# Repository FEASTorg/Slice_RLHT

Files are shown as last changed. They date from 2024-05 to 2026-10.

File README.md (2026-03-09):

# Sice RLHT

Relay Heating Element Controller Slice for BREAD.

## Introduction

[Provide a brief introduction to the project, including the motivation and goals. Explain the significance and context of the research.]

## Project Overview

[Describe the project in more detail. This section can be split into subsections if necessary.]

## Installation

[Provide instructions for installing any necessary software or hardware components.]

## Usage

[Explain how to use the project. Include examples and screenshots if applicable.]

### Basic Usage

[Provide basic usage instructions.]

### Advanced Usage

[Provide advanced usage instructions, including any optional features or configurations.]

## Documentation

[Link to the detailed documentation if available. Provide instructions on how to access and navigate the documentation.]

## Contributing

[Explain how others can contribute to the project. Include guidelines for submitting issues, pull requests, and any coding standards.]

### Code of Conduct

[Link to the project's code of conduct if available.]

## License

[State the license under which the project is distributed. Include a link to the full license text.]

## Acknowledgements

[Acknowledge any contributors, collaborators, funding sources, or organizations that supported the project.]

## Contact

[Provide contact information for the project maintainer(s) or lead researcher(s). Include an email address or a link to a contact form.]

---

<div align="center">
  <p>
    
    
  </p>
</div>

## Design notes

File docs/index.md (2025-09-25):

---
title: "Slice RLHT Documentation"
description: "Overview and entry page for Slice RLHT project documentation."
nav_exclude: true
---

Welcome to the Slice RLHT project documentation.

## Board Renders

<figure style="display:inline-block; text-align:center; margin:10px;">
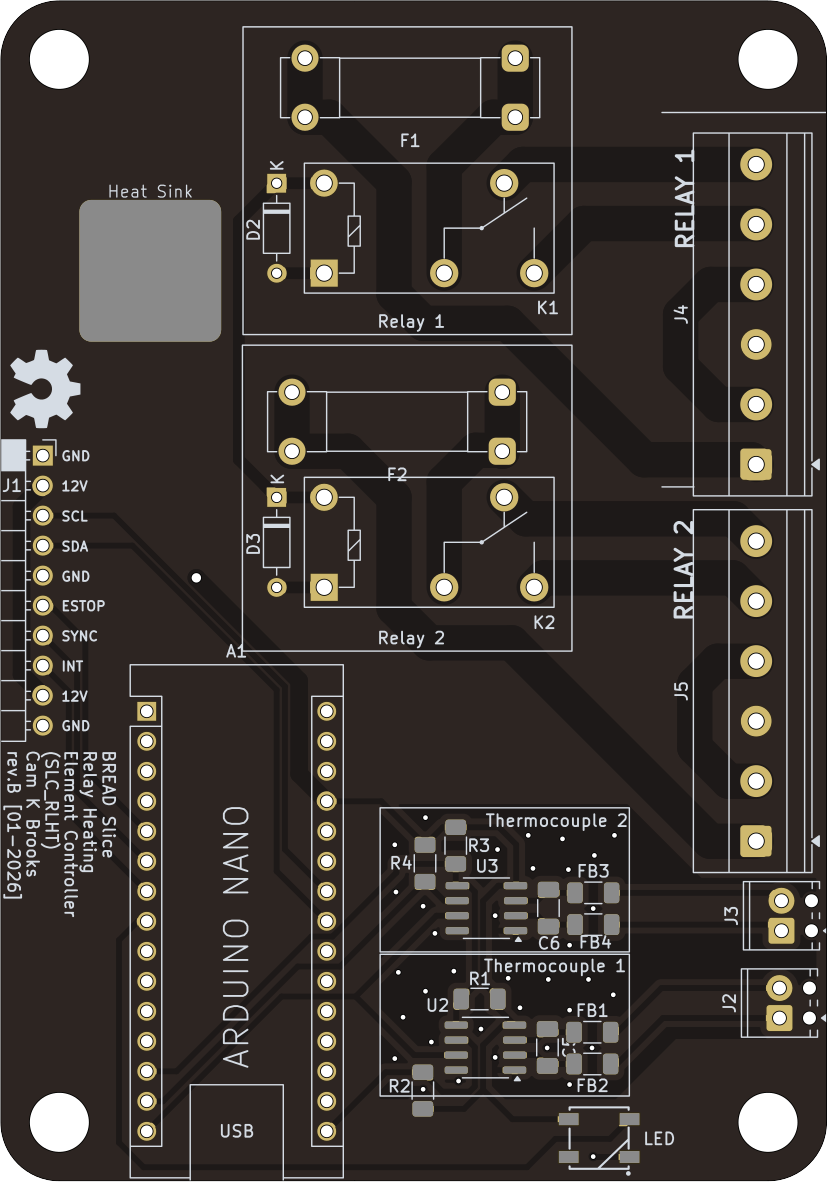
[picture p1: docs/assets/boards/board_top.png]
Board Top
  
  <figcaption>Top</figcaption>
</figure>

<figure style="display:inline-block; text-align:center; margin:10px;">
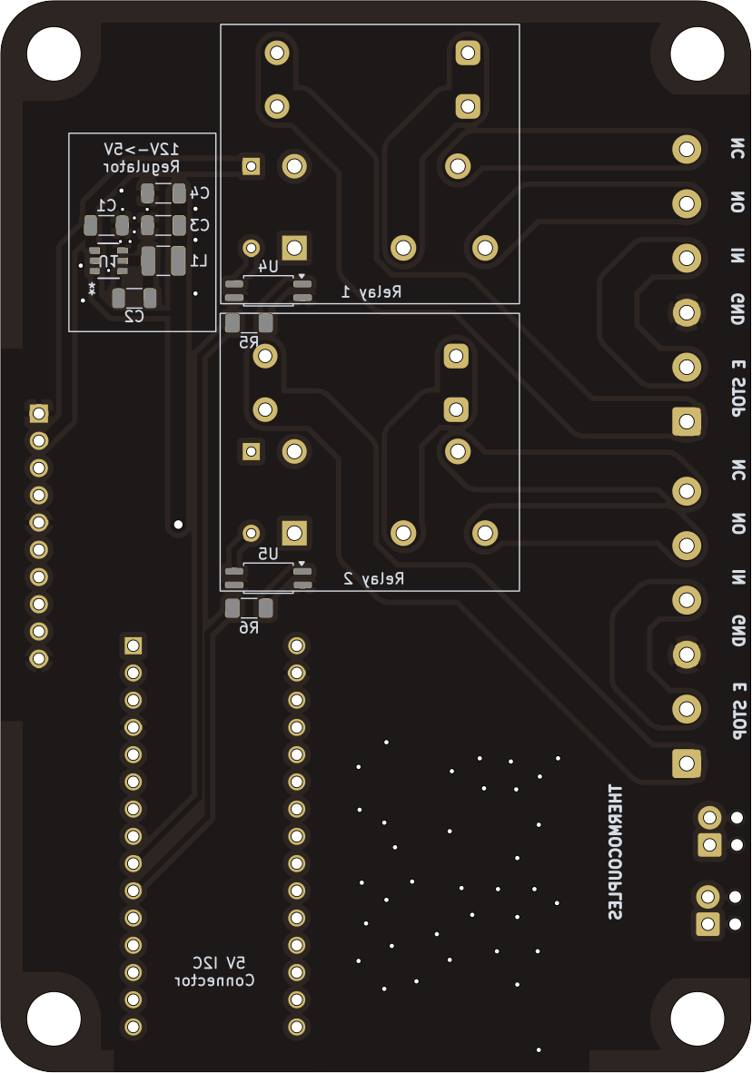
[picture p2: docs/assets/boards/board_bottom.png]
Board Bottom
  
  <figcaption>Bottom</figcaption>
</figure>

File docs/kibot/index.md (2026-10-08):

---
title: "KiBot Outputs"
description: "Index for KiBot-generated PCB artifacts."
layout: "page"
---

These are the docs & KiBot Outputs for Slice RLHT

The following files were generated from the latest PCB build:

- [Schematic.pdf](./Schematic.pdf)
- [PCB.pdf](./PCB.pdf)
- [kibot.log](./kibot.log)
- [BREAD_Slice-bom.html](./BREAD_Slice-bom.html)
- [BREAD_Slice-ibom.html](./BREAD_Slice-ibom.html)

_Last updated automatically on 2026-10-08 at 03:28:19 UTC by KiBot via GitHub Actions._

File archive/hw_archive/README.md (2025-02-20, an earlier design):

# Historical Hardware Progression

Cam notes:

- 2022-05-19 we dont have any in the lab to my knowledge
- 2022-06-30 is the green ones in the lab
- recent is the most recent one from Finn, has glass fuse
- still missing files for one with blade fuse

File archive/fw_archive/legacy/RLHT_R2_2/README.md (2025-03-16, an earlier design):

# RLHT R2.2 Firmware Docs

Notes on the firmware for relay heater slice.

## Commands

This system supports several types of serial commands that allow the user to control various aspects of the system, such as mode selection, relay input, heater setpoints, PID tuning, and emergency stop.

### 1. Mode Commands (`M`)

- **Format**: `M <mode>`
  - **Example**: `M 0` to switch to CONTROL mode (automatic PID control)
  - **Example**: `M 1` to switch to WRITE mode (manual control of relay inputs)

### 2. Write Relay Input (`W`)

- **Format**: `W <relay> <value>`
  - **Example**: `W 1 75` to set relay 1 input to 75% (value is clamped between 0 and 100)
  - **Example**: `W 2 50` to set relay 2 input to 50%

### 3. Heater Setpoint (`H`)

- **Format**: `H <heater> <setpoint>`
  - **Example**: `H 1 150.5` to set heater 1's temperature setpoint to 150.5°C
  - **Example**: `H 2 200` to set heater 2's temperature setpoint to 200°C

### 4. PID Tuning (`P`)

- **Format**: `P <heater> <Kp>,<Ki>,<Kd>`
  - **Example**: `P 1 2.5,0.1,0.01` to update PID values for heater 1 (Kp=2.5, Ki=0.1, Kd=0.01)
  - **Example**: `P 2 3.0,0.2,0.02` to update PID values for heater 2 (Kp=3.0, Ki=0.2, Kd=0.02)

### 5. Thermo Select (`S`)

- **Format**: `S <relay> <thermo>`
  - **Example**: `S 1 1` to set relay 1 to read from thermocouple 1
  - **Example**: `S 2 2` to set relay 2 to read from thermocouple 2

### Invalid Commands

- Any command that does not match the above patterns will result in an error message: `Invalid command!`

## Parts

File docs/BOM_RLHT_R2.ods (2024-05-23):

References | Value | Footprint | Quantity | URL
C1, C3, C4 | 22uF | C_1206_3216Metric | 3 | https://www.digikey.ca/en/products/detail/samsung-electro-mechanics/CL31A226KAHNNNE/3888705
C5, C6 | 0.01 uF | C_1206_3216Metric | 2 | https://www.digikey.ca/en/products/detail/walsin-technology-corporation/1206B103J500CT/9355096
C2 | 100nF | C_1206_3216Metric | 1 | https://www.digikey.ca/en/products/detail/samsung-electro-mechanics/CL31B104KBCNNNC/3886675
L1 | 4.7uH | L_1210_3225Metric | 1 | https://www.digikey.ca/en/products/detail/tdk-corporation/BCL322520RT-4R7M-D/15849704
D2, D3 | General_Purpose_Diode | D_DO-35_SOD27_P7.62mm_Horizontal | 2 | https://www.digikey.ca/en/products/detail/onsemi/1N914B/978757
D1 | WS2812B_5050 | WS2812-5050-4PIN | 1 | https://www.digikey.ca/en/products/detail/sparkfun-electronics/COM-16347/11630204
U2, U5 | TCMT1100 | SOP-4_4.4x2.6mm_P1.27mm | 2 | https://www.digikey.ca/en/products/detail/vishay-semiconductor-opto-division/TCMT1100/1738630
U3, U4 | MAX6675ISA+ | SOIC127P600X175-8N | 2 | https://www.digikey.ca/en/products/detail/maxim-integrated/MAX6675ISA/1513517
U1 | AP63205WU-7 | TSOT-23-6 | 1 | https://www.digikey.ca/en/products/detail/diodes-incorporated/AP63205WU-7/9858424
F1, F2 | 10A | Glass Fuse Clip x2 (5x20MM) | 4 | https://www.digikey.ca/en/products/detail/bel-fuse-inc/FC-211-BRIGHT-TIN/622587
A1 | Arduino_Nano_v3.x | Arduino_Nano | 1 | https://www.amazon.ca/ELEGOO-Arduino-ATmega328P-Without-Compatible/dp/B0713XK923
FB1, FB2, FB3, FB4 | Ferrite_Bead_Small | R_1206_3216Metric | 4 | https://www.digikey.ca/en/products/detail/w%C3%BCrth-elektronik/74279215/1639033
K1, K2 | G5Q-1 | Relay_SPDT_Omron-G5Q-1 | 2 | https://www.digikey.ca/en/products/detail/omron-electronics-inc-emc-div/G5Q-14-DC12/355243
HS1 | Heatsink_Pad (optional) | Thermal Pad | 1 | https://www.digikey.ca/en/products/detail/assmann-wsw-components/V2017B/3511410
J4 | Term_PressFit_Phoenix_Contact | Term_PressFit_3.5mm_H_ENDCAP_PC | 1 (4x) | https://www.digikey.ca/en/products/detail/phoenix-contact/1990753/2527254
J3, J11, J12 | Term_PressFit_Phoenix_Contact | Term_PressFit_3.5mm_H_PC
J1 | Conn_01x10_Female | PinSocket_1x10_P2.54mm_Horizontal | 1 | https://www.digikey.ca/en/products/detail/sullins-connector-solutions/PPTC101LGBN-RC/775904
J2 | I2C_01x04 | JST_SH_SM04B-SRSS-TB_1x04-1MP_P1.00mm_Horizontal | 1 | https://www.digikey.ca/en/products/detail/jst-sales-america-inc/SM04B-SRSS-TB/926710
J6, J7, J8, J9, J10, J13, J14, J15, J16, J17, J18 | Term_PressFit_Phoenix_Contact | Term_PressFit_5mm_H_PC_HVRELAY | 2 (6x) | https://www.digikey.ca/en/products/detail/phoenix-contact/1991011/2527265
J5 | Term_PressFit_Phoenix_Contact | Term_PressFit_5mm_H_ENDCAP_PC_HVRELAY
 | 10A | Glass Fuse 5x20mm | 2 | https://www.digikey.ca/en/products/detail/bel-fuse-inc/5ST-10-R/1009028

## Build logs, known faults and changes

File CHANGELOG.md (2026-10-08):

# Changelog

All notable changes to Slice RLHT are documented here.

This project did not use formal release tags through most of its history, so this changelog is organized by dated development eras rather than semantic-version releases.

## [Unreleased]

### Added

- Added this curated root changelog, distilled from the complete Git history.

### Changed

- Updated active firmware metadata to reference CRUMBS `0.12.4` and
  `bread-crumbs-contracts` `0.4.3`.
- Split the `relayControlLogic()` shared-state snapshot into three short
  interrupt-masked windows (worst case ~18 bytes instead of ~44). Long
  `noInterrupts()` windows delay TWI ISR entry and force a clock stretch
  that Linux SBC I2C masters mishandle — the confirmed cause of the DCMT
  query failures (feastorg/Slice_DCMT#3). Preventive hardening; RLHT
  itself measured 0 failures in bench testing.

### Fixed

- The PID integral survived `SET_SETPOINTS(0, 0)`, a command-watchdog trip
  and an e-stop. A heater kept running after the safe state, and resumed its
  old duty when a trip cleared or an e-stop was released, decaying only
  through Ki, over tens of seconds, and never with Ki = 0. In closed loop, a
  heater with a setpoint of 0 or less is now held off with its PID in
  manual, and a trip or an e-stop puts both PIDs in manual at once, so
  heating starts from 0 when a setpoint returns (#13). A setpoint of 0 now
  means off, where it was a 0 °C target that only sub-zero surroundings
  could heat to.
- Gen1 boards have one relay, on D6, with D7 not connected, but the gen1
  firmware ran a second heater channel on D7 and reported it in `GET_STATE`
  as if it were heating. Gen1 builds now define no `RELAY2`, never drive D7,
  and report channel 2 as off with a 0 on-time; channel-2 commands are still
  accepted (#21). `docs/hardware-revisions.md` records each generation's
  boards and pin map.
- A command could be lost when its frame landed while the main loop was
  running a heater: `relayControlLogic()` copied mode, setpoints, PID gains,
  thermocouple selects and the open-loop on-times, then wrote the copies
  back over anything the I2C handlers had written in between. On a gen1
  rig, 10 of 16 open-loop duty frames were lost this way, `set_open_duty_pct
  0/0` among them, so a controller's safe state did not stop the heater.
  The main loop now only reads those fields; the PIDs work on their own
  variables, and the closed-loop output is published only while the mode is
  still closed loop (#14).
- Entering closed loop seeded the PID from the open-loop on-time, so a
  heater resumed the open-loop duty and, with Ki = 0, stayed there. Closed
  loop now starts from 0, and the PID switches to automatic only with a
  fresh input, so a non-zero Kd no longer adds a one-sample kick from the
  last closed-loop reading (#17).
- Entering open loop kept the PID's last on-time as the open-loop duty: the
  heater kept running with no setpoint to stop it, and `SET_SETPOINTS(0, 0)`
  did nothing in open loop. `SET_MODE` and serial `MODE=` now start open
  loop at 0; re-sending open loop while already in it keeps the duty.

### Notes

- The root README still contains template placeholder sections.
- No formal release tags or semantic-versioned hardware/firmware releases have
  been cut in this repository yet.

## [2026-04-01 to 2026-05-12] Firmware Hardening And Dependency Cleanup

### Added

- Active PlatformIO firmware project under `firmware/`, with separate `include/`
  and `src/` trees.
- CRUMBS-based RLHT firmware using the published `bread-crumbs-contracts`
  package.
- PlatformIO environments for gen1/gen2 hardware on Arduino Nano and Nano Every:
  - `gen1_nano`
  - `gen2_nano`
  - `gen1_nanoevery`
  - `gen2_nanoevery`
- Dual-relay control firmware with:
  - closed-loop PID temperature control
  - open-loop relay on-time control
  - dual MAX6675 thermocouple reads
  - configurable thermocouple-to-relay selection
  - configurable relay periods
  - serial command interface
  - CRUMBS handlers and replies for mode, setpoints, PID, periods, thermocouple
    selection, open-loop duty, state, version, and capabilities
- Emergency-stop handling with internal pull-up input mode, debounce, relay
  shutdown, and status LED behavior on supported hardware.
- AVR/megaAVR watchdog support with a 1 second timeout.
- Static serial command buffer to avoid heap allocation from Arduino `String`.
- KiCad hardware project under `hardware/`, including hierarchical sheets for
  relay, thermistor, and MAX31855K circuitry.
- Checked-in fabrication outputs under `hardware/outputs/` plus
  `hardware/outputs.zip`.
- KiBot hardware automation config and Makefile targets for ERC, DRC,
  fabrication outputs, BOMs, drill files, position files, and board renders.
- GitHub Pages-style docs scaffold under `docs/`, including generated board
  render images.
- Historical hardware and firmware archives under `archive/`.

### Changed

- Moved the active firmware from sketch-era `.ino` layouts to a PlatformIO C++
  project.
- Switched from local contract header copies to published BREAD/RLHT contracts.
- Made I2C address, hardware generation, and debug behavior configurable through
  build flags.
- Centralized relay period writes and tightened relay period types.
- Mapped local control modes to contract-defined enums.
- Changed firmware version reporting to use the canonical contract version.
- Updated timing fields to align with Arduino `millis()` semantics.
- Updated docs automation to use lowercase `feastorg` organization casing.

### Fixed

- Reduced e-stop race and bounce issues with debounce and interrupt-guarded
  shared state.
- Reduced heap-fragmentation risk in serial command parsing by removing Arduino
  `String` input handling.
- Guarded serial command trimming against empty input.
- Reduced thermocouple timing drift by using relative interval updates.
- Replaced raw invalid-temperature sentinel handling with the protocol-defined
  `BREAD_INVALID_I16`.
- Avoided repeated `FastLED.show()` calls when the status LED state has not
  changed.
- Removed a no-op relay-control path.

### Removed

- Removed drift-prone local copies of BREAD/RLHT contract headers after the
  published contract cutover.
- Removed remaining active hardware backup zip files from the main hardware
  tree.

## [2026-03-09 to 2026-04-01] PlatformIO And Contract Cutover

### Added

- Clean PlatformIO firmware layout with:
  - `firmware/platformio.ini`
  - `firmware/include/config.h`
  - `firmware/include/config_hardware.h`
  - `firmware/include/globals.h`
  - `firmware/src/main.cpp`
  - `firmware/src/rlht_handlers.cpp`
  - `firmware/src/serialCommands.cpp`
  - `firmware/src/printSerialOutputRLHT.cpp`
- Initial local BREAD/RLHT contract headers during the migration.
- Published contract dependency usage after the migration stabilized.
- Capability reply support.
- Build profiles for Nano and Nano Every, split by RLHT hardware generation.
- Firmware workspace ignores and VS Code extension recommendations.

### Changed

- Archived the previous gen2 firmware before replacing the active firmware with
  the new CRUMBS-based implementation.
- Added hardware-generation selection to firmware build configuration.
- Added build-flag based I2C address selection.
- Moved CRUMBS debug behavior into build configuration.
- Internalized CRUMBS context handling.
- Cleaned up serial output and command string handling.
- Bumped CRUMBS to `0.12.0` and `bread-crumbs-contracts` to `0.4.1`.

### Fixed

- Added development-context and version checks during the contract migration.
- Debounced e-stop handling and switched the e-stop input to internal pull-up.
- Centralized relay period writes and tightened unsigned period handling.
- Reduced timing drift in thermocouple reads.
- Switched invalid temperature serialization to the protocol-defined invalid
  value.

### Removed

- Removed temporary local contract headers once published packages were in use.
- Removed temporary firmware placeholder files after the active PlatformIO tree
  landed.

## [2025-09-24 to 2026-02-01] Archive And Documentation Reorganization

### Added

- GitHub Actions docs pipeline using shared `bread-infra` workflows.
- Docs scaffold under `docs/`, including architecture, testing, changelog, TODO,
  KiBot, and index pages.
- Generated board render images and generated KiBot index page.
- `hardware/config.kibot.yaml` for KiBot output generation.
- `hardware/Makefile` for hardware validation and fabrication-output targets.
- Top-level hardware archive organization, later consolidated under
  `archive/hw_archive/`.
- Legacy `RLHT_R1` sketch in the firmware archive.

### Changed

- Moved the BOM spreadsheet from `documentation/` to `docs/`.
- Renamed generated hardware output paths from `Gerbers/` to `outputs/`.
- Renamed `Gerbers.zip` to `outputs.zip`.
- Split firmware into generation-oriented gen1/gen2 layouts before the later
  PlatformIO cutover.
- Rearranged archives so historical firmware lives under `archive/fw_archive/`
  and historical hardware lives under `archive/hw_archive/`.
- Revised the active KiCad hardware against newer template/library expectations.

### Removed

- Removed old active hardware backup zips that existed remotely.
- Removed older duplicate archive locations after the `archive/` layout was
  established.
- Removed an obsolete hardware reference image and archived binary backup zips.

## [2025-02-19 to 2025-04-19] CRUMBS Prototype And Firmware Revision Era

### Added

- Multiple firmware revision snapshots, including R2 new, R2.1, R2.2, and older
  R2/R3 code paths.
- Historical hardware snapshots for OSF dates and a Finn-derived recent design.
- Notes describing known hardware progression and lab board context.
- Experimental CRUMBS-based firmware sketch.
- Firmware modules for message handling, request handling, serial output, and
  relay actuation.

### Changed

- Renamed and organized firmware revisions as development moved from R2 new to
  R2.1/R2.2 and then toward a CRUMBS-based active firmware.
- Moved older firmware revisions into legacy folders.
- Refactored the active firmware away from a single monolithic sketch.
- Moved debug macros into configuration.
- Updated active and archived KiCad files during hardware/library maintenance.

### Fixed

- Fixed e-stop ISR behavior in the CRUMBS firmware prototype.
- Separated e-stop processing from the main loop.
- Modularized relay actuation.

## [2024-05-23 to 2024-09-30] Initial Hardware And Firmware Bring-Up

### Added

- Initial GPL-licensed repository with README, KiCad board, schematic, project
  files, and early BOM artifacts.
- Initial generated board-house outputs, including copper, mask, paste,
  silkscreen, edge cuts, drill files, and Gerber job data.
- Early Arduino firmware sketches for `RLHT_R2` and `RLHT_R3`.
- JLCPCB Rev-A order package and generated Gerber artifacts.
- Hierarchical KiCad sheets for MAX31855K thermocouple, relay, and thermistor
  circuitry.

### Changed

- Revised the KiCad board and schematic heavily during terminal and review
  updates.
- Reorganized generated fabrication outputs during the Rev-A preparation.

### Removed

- Removed the initial placeholder firmware file once real firmware sketches were
  added.
- Removed an early temporary BOM artifact during hardware review cleanup.

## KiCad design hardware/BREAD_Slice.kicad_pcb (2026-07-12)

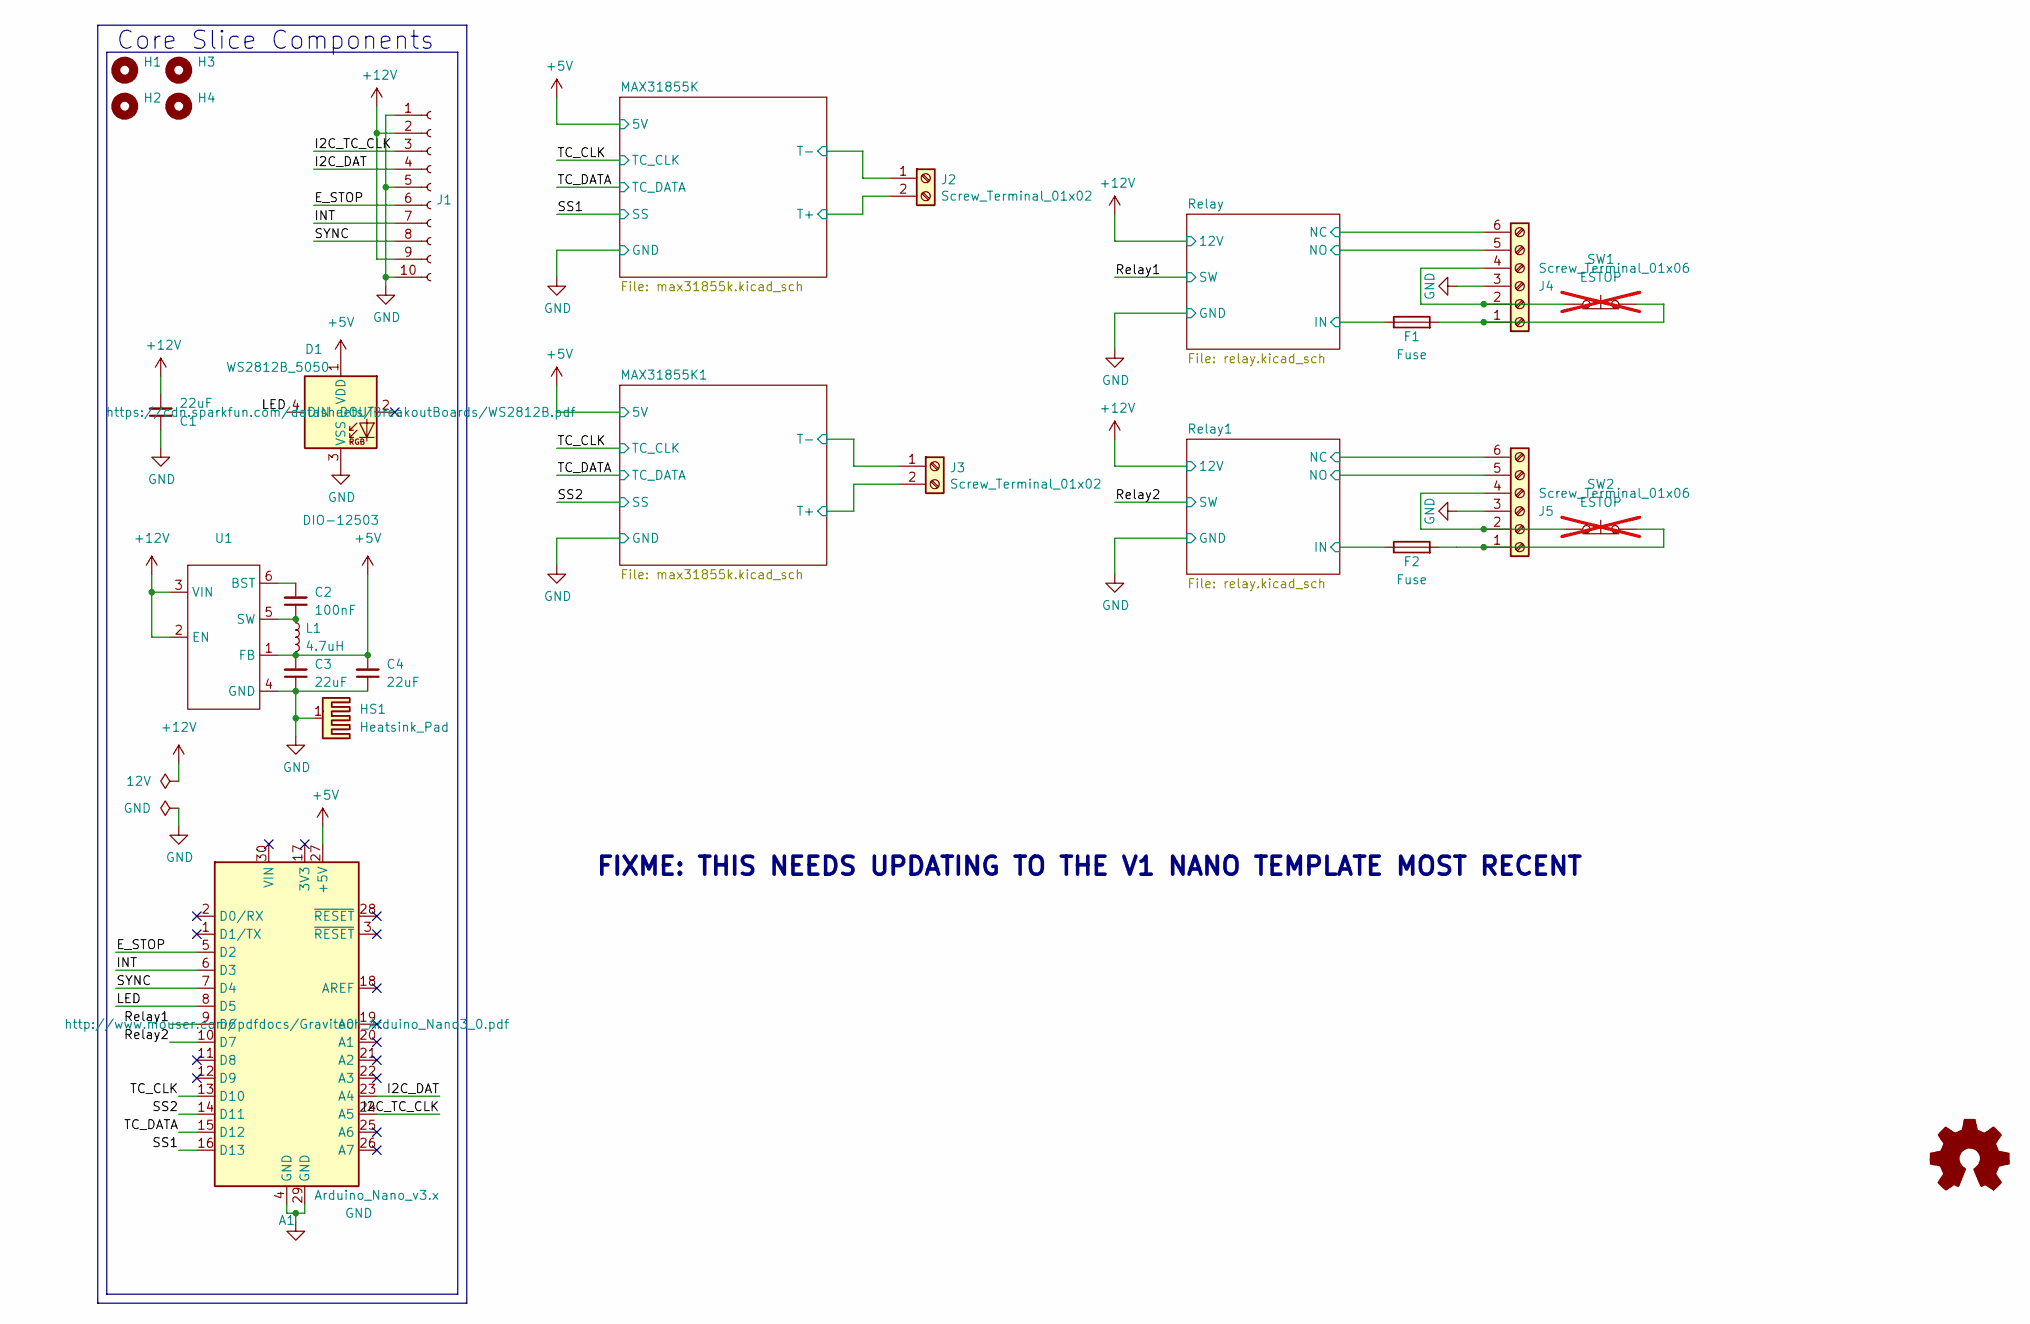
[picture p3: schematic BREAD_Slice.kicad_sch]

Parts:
A1: Arduino_Nano_v3.x; Arduino_Nano
C1, C3, C4: 22uF; C_1206_3216Metric
C2: 100nF; C_1206_3216Metric
D1: WS2812B_5050; WS2812-5050-4PIN
F1, F2: Fuse; Fuseholder_Clip-5x20mm_Bel_FC-203-22_Lateral_P17.80x5.00mm_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
H1, H2, H3, H4: MountingHole; MountingHole_5mm
HS1: Heatsink_Pad; Thermal_Pad
J1: Conn_01x10_Female; PinSocket_1x10_P2.54mm_Horizontal
J2, J3: Screw_Terminal_01x02; TerminalBlock_Phoenix_MPT-0,5-2-2.54_1x02_P2.54mm_Horizontal
J4, J5: Screw_Terminal_01x06; TerminalBlock_Phoenix_MKDS-1,5-6-5.08_1x06_P5.08mm_Horizont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
L1: 4.7uH; L_1210_3225Metric
SW1, SW2: ESTOP; not fitted
U1: SOIC_05WU-7_DIO

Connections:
+5V: A1.27 (+5V), C3.2, C4.2, D1.1 (VDD), L1.2, U1.1 (FB); also elsewhere on the board
+12V: C1.2, J1.2, J1.9, U1.2 (EN), U1.3 (VIN); also elsewhere on the board
/E_STOP: A1.5 (D2), J1.6
/I2C_DAT: A1.23 (A4), J1.4
/I2C_TC_CLK: A1.24 (A5), J1.3
/INT: A1.6 (D3), J1.7
/LED: A1.8 (D5), D1.4 (DIN)
/MAX31855K1/T+: J3.2; also elsewhere on the board
/MAX31855K1/T-: J3.1; also elsewhere on the board
/MAX31855K/T+: J2.2; also elsewhere on the board
/MAX31855K/T-: J2.1; also elsewhere on the board
/Relay1: A1.9 (D6); also elsewhere on the board
/Relay1/IN: F2.1; also elsewhere on the board
/Relay1/NC: J5.6; also elsewhere on the board
/Relay1/NO: J5.5; also elsewhere on the board
/Relay2: A1.10 (D7); also elsewhere on the board
/Relay/IN: F1.1; also elsewhere on the board
/Relay/NC: J4.6; also elsewhere on the board
/Relay/NO: J4.5; also elsewhere on the board
/SS1: A1.16 (D13); also elsewhere on the board
/SS2: A1.14 (D11); also elsewhere on the board
/SYNC: A1.7 (D4), J1.8
/TC_CLK: A1.13 (D10); also elsewhere on the board
/TC_DATA: A1.15 (D12); also elsewhere on the board
GND: A1.4 (GND), A1.29 (GND), C1.1, C3.1, C4.1, D1.3 (VSS), HS1.1, J1.1, J1.5, J1.10, J4.3, J5.3, U1.4 (GND); also elsewhere on the board
unnamed: F1.2, J4.1, SW1.2 (B)
unnamed: J4.2, J4.4, SW1.1 (A)
unnamed: F2.2, J5.1, SW2.2 (B)
unnamed: J5.2, J5.4, SW2.1 (A)
unnamed: C2.2, U1.6 (BST)
unnamed: C2.1, L1.1, U1.5 (SW)

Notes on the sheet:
FIXME: THIS NEEDS UPDATING TO THE V1 NANO TEMPLATE MOST RECENT
Core Slice Components

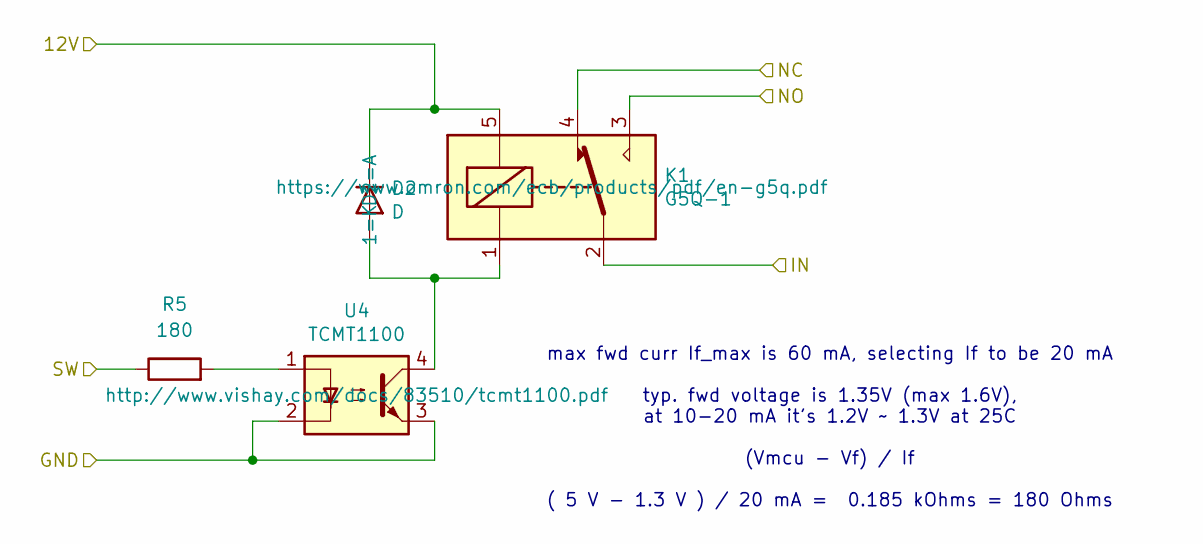
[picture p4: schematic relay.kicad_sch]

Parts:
D2: D; D_DO-35_SOD27_P7.62mm_Horizontal
K1: G5Q-1; Relay_SPDT_Omron-G5Q-1
R5: 180; R_1206_3216Metric_Pad1.30x1.75mm_HandSolder
U4: TCMT1100; SOP-4_4.4x2.6mm_P1.27mm

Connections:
+12V: D2.1 (K), K1.5; also elsewhere on the board
/Relay1: R5.1; also elsewhere on the board
/Relay/IN: K1.2; also elsewhere on the board
/Relay/NC: K1.4; also elsewhere on the board
/Relay/NO: K1.3; also elsewhere on the board
GND: U4.2, U4.3; also elsewhere on the board
unnamed: D2.2 (A), K1.1, U4.4
unnamed: R5.2, U4.1

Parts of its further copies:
D3: D; D_DO-35_SOD27_P7.62mm_Horizontal
K2: G5Q-1; Relay_SPDT_Omron-G5Q-1
R6: 180; R_1206_3216Metric_Pad1.30x1.75mm_HandSolder
U5: TCMT1100; SOP-4_4.4x2.6mm_P1.27mm

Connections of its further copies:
+12V: D3.1 (K), K2.5; also elsewhere on the board
/Relay1/IN: K2.2; also elsewhere on the board
/Relay1/NC: K2.4; also elsewhere on the board
/Relay1/NO: K2.3; also elsewhere on the board
/Relay2: R6.1; also elsewhere on the board
GND: U5.2, U5.3; also elsewhere on the board
unnamed: D3.2 (A), K2.1, U5.4
unnamed: R6.2, U5.1

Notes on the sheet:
max fwd curr If_max is 60 mA, selecting If to be 20 mA typ. fwd voltage is 1.35V (max 1.6V), at 10-20 mA it's 1.2V ~ 1.3V at 25C (Vmcu - Vf) / If ( 5 V - 1.3 V ) / 20 mA = 0.185 kOhms = 180 Ohms

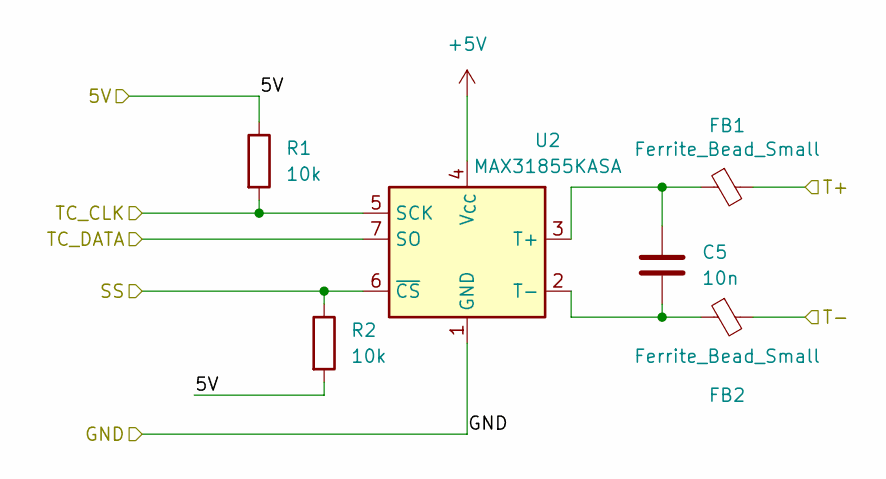
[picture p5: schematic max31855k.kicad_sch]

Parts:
C5: 10n; C_1206_3216Metric_Pad1.33x1.80mm_HandSolder
FB1, FB2: Ferrite_Bead_Small; R_1206_3216Metric_Pad1.30x1.75mm_HandSolder
R1, R2: 10k; R_1206_3216Metric_Pad1.30x1.75mm_HandSolder
U2: MAX31855KASA; SOIC-8_3.9x4.9mm_P1.27mm

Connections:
+5V: R1.1, R2.2, U2.4 (V_{CC}); also elsewhere on the board
/MAX31855K/T+: FB1.2; also elsewhere on the board
/MAX31855K/T-: FB2.2; also elsewhere on the board
/SS1: R2.1, U2.6 (~CS); also elsewhere on the board
/TC_CLK: R1.2, U2.5 (SCK); also elsewhere on the board
/TC_DATA: U2.7 (SO); also elsewhere on the board
GND: U2.1 (GND); also elsewhere on the board
unnamed: C5.1, FB1.1, U2.3 (T+)
unnamed: C5.2, FB2.1, U2.2 (T-)

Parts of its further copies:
C6: 10n; C_1206_3216Metric_Pad1.33x1.80mm_HandSolder
FB3, FB4: Ferrite_Bead_Small; R_1206_3216Metric_Pad1.30x1.75mm_HandSolder
R3, R4: 10k; R_1206_3216Metric_Pad1.30x1.75mm_HandSolder
U3: MAX31855KASA; SOIC-8_3.9x4.9mm_P1.27mm

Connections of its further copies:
+5V: R3.1, R4.2, U3.4 (V_{CC}); also elsewhere on the board
/MAX31855K1/T+: FB3.2; also elsewhere on the board
/MAX31855K1/T-: FB4.2; also elsewhere on the board
/SS2: R4.1, U3.6 (~CS); also elsewhere on the board
/TC_CLK: R3.2, U3.5 (SCK); also elsewhere on the board
/TC_DATA: U3.7 (SO); also elsewhere on the board
GND: U3.1 (GND); also elsewhere on the board
unnamed: C6.1, FB3.1, U3.3 (T+)
unnamed: C6.2, FB4.1, U3.2 (T-)

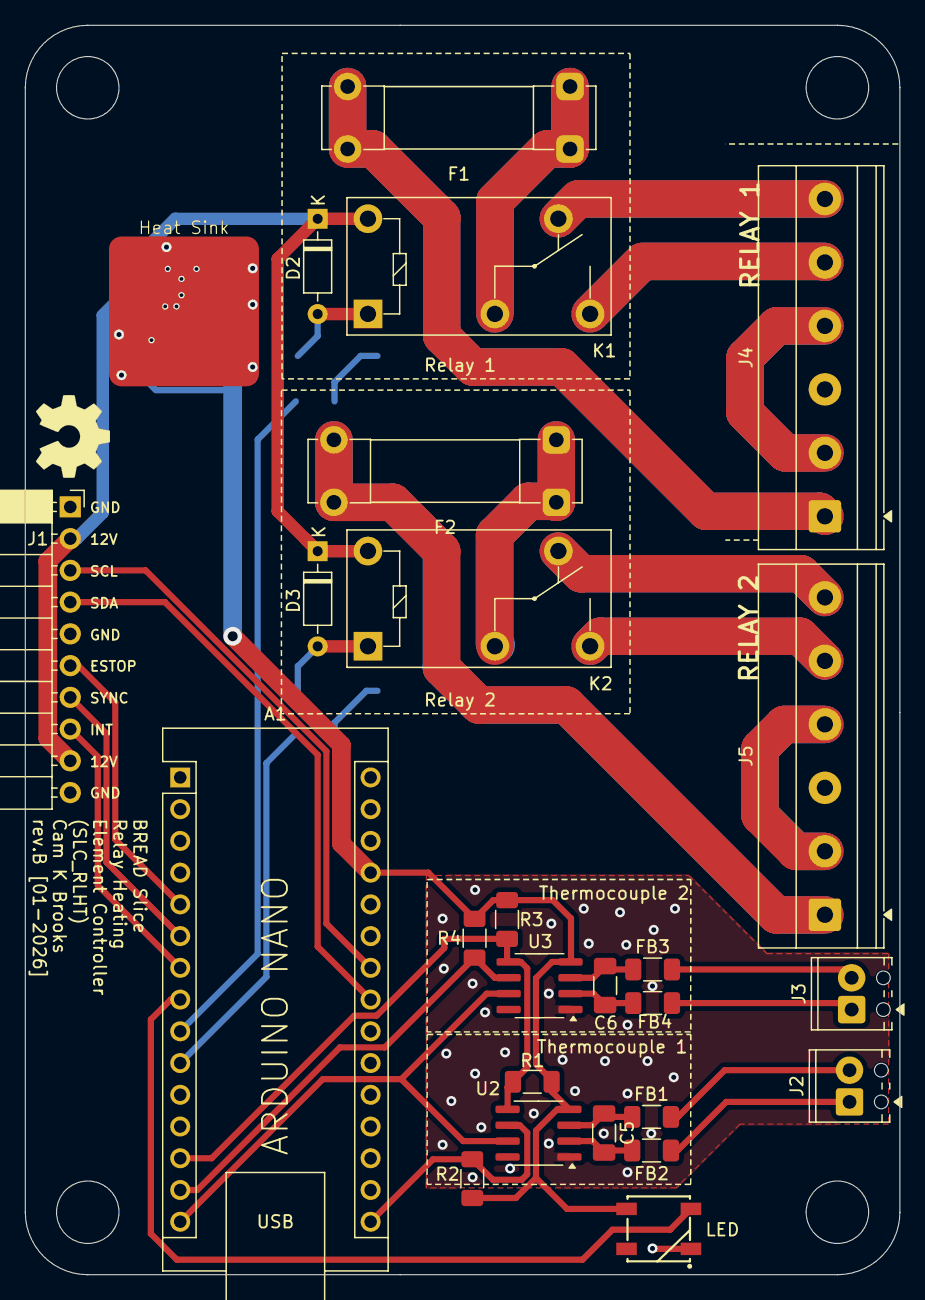
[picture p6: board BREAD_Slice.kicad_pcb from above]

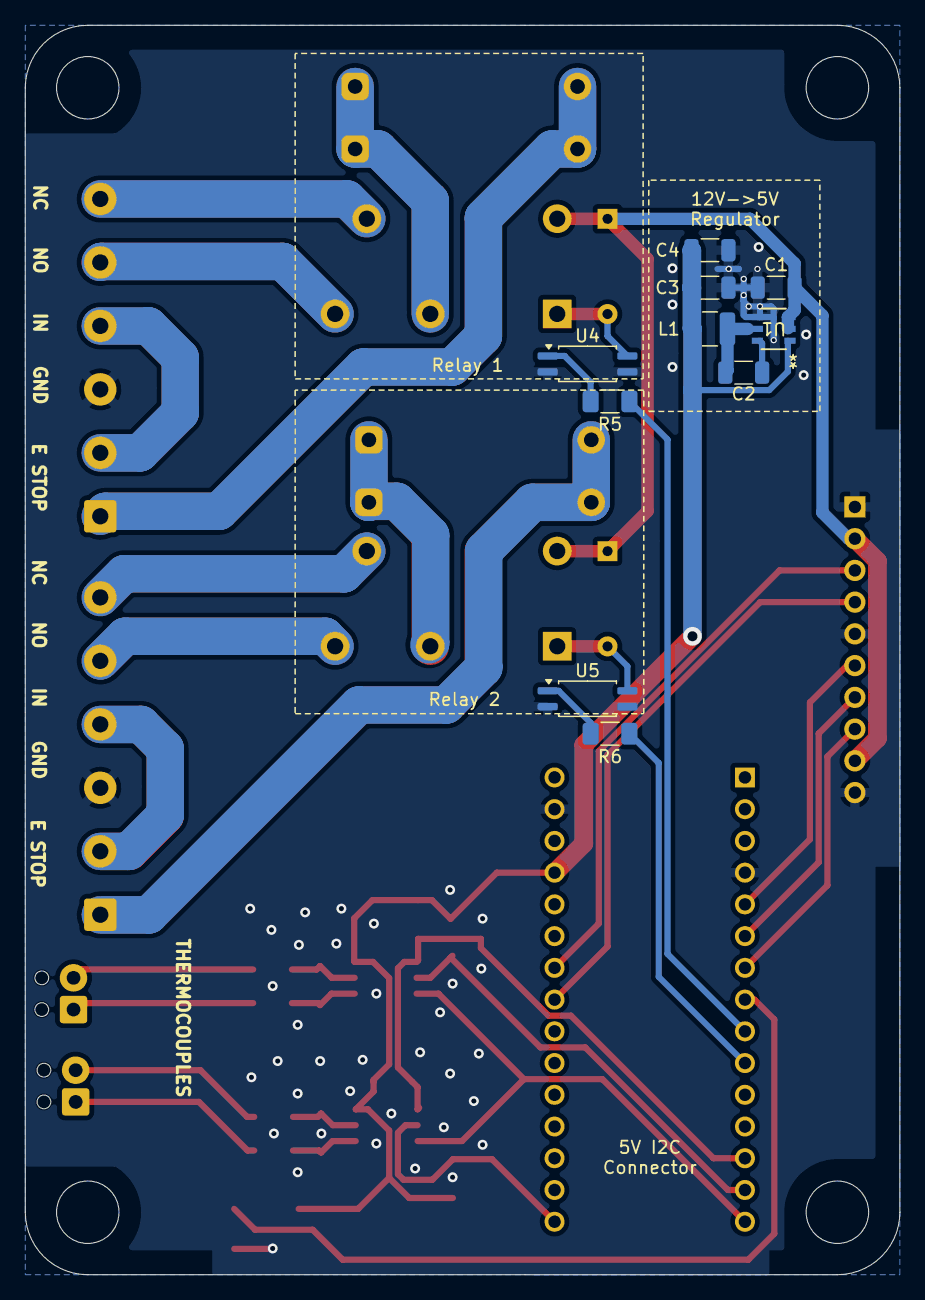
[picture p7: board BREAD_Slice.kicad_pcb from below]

Board: 2 copper layers, 70.0 x 100.0 mm, 41 parts (10 on the bottom side), 39 nets.

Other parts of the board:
Logo1: Logo_Open_Hardware_Small; OSHW-Symbol_6.7x6mm_SilkScreen

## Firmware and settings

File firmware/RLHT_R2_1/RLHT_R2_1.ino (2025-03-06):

#include <Wire.h>
#include "max6675.h"
#include <FastLED.h>
#include <PID_v1.h>

#define I2C_ADR 10

#define ESTOP 2
#define LED_PIN 5
#define TC_CS1 10
#define TC_CS2 11
#define TC_DATA 12
#define TC_CLK 13
#define RELAY1 6
#define RELAY2 7

#define THERMO_UPDATE_TIME_MS 300
#define SERIAL_UPDATE_TIME_MS 1000

long lastThermoRead = 0;
long lastSerialPrint = 0;

bool E_STOP = false;

CRGB led;
int hue = 0;

struct RLHT_t
{
  double heatSetpoint_1 = 0; // set desired temperature for heater 1 (if using relay as heater actuator)
  double relay1Input;        // input to relay 1 taken from selected thermocouple
  double rOnTime_1;          // time relay is on in ms (0-period)
  int rPeriod_1 = 2000;      // duration of relay 1 cycle in ms (1000ms = 1s)
  double Kp_1 = 0;           // PID proportional gain for heater 1
  double Ki_1 = 0;           // PID integral gain for heater 1
  double Kd_1 = 0;           // PID derivative gain for heater 1
  double heatSetpoint_2 = 0;
  double relay2Input;
  double rOnTime_2;
  int rPeriod_2 = 2000;
  double Kp_2 = 0;
  double Ki_2 = 0;
  double Kd_2 = 0;
  double thermo1; // thermocouple 1 measurement
  double thermo2;
  char thermoSelect[2] = {1, 2}; // select which thermocouples pair with relays {relay1, relay2}
} RLHT, RLHT_old;

union FLOATUNION_t // Define a float that can be broken up and sent via I2C
{
  float number;
  uint8_t bytes[4];
};

// initialize the Thermocouples
MAX6675 CH1(TC_CLK, TC_CS1, TC_DATA);
MAX6675 CH2(TC_CLK, TC_CS2, TC_DATA);

// Specify the links and initial tuning parameters
// PID myPID(&Input, &Output, &Setpoint, Kp, Ki, Kd, DIRECT);
PID relay1PID(&(RLHT.relay1Input), &(RLHT.rOnTime_1), &(RLHT.heatSetpoint_1), RLHT.Kp_1, RLHT.Ki_1, RLHT.Kd_1, DIRECT);
PID relay2PID(&(RLHT.relay2Input), &(RLHT.rOnTime_2), &(RLHT.heatSetpoint_2), RLHT.Kp_2, RLHT.Ki_2, RLHT.Kd_2, DIRECT);

unsigned long relay1StartTime;
unsigned long relay2StartTime;

enum Mode
{
  CONTROL,
  WRITE
};

Mode currentMode = CONTROL;

void estop()
{
  if (digitalRead(ESTOP) == HIGH) // when set to HIGH state
  {
    led = CRGB::Red;
    FastLED.show();

    // save states
    RLHT_old.heatSetpoint_1 = RLHT.heatSetpoint_1;
    RLHT_old.heatSetpoint_2 = RLHT.heatSetpoint_2;
    RLHT_old.rOnTime_1 = RLHT.rOnTime_1;
    RLHT_old.rOnTime_2 = RLHT.rOnTime_2;

    // set critical states to zero and turn off relays
    RLHT.heatSetpoint_1 = 0;
    RLHT.heatSetpoint_2 = 0;
    RLHT.rOnTime_1 = 0;
    RLHT.rOnTime_2 = 0;

    digitalWrite(RELAY1, LOW);
    digitalWrite(RELAY2, LOW);

    E_STOP = true;
    Serial.println("ESTOP PRESSED!");
  }
  else // when ESTOP state is LOW
  {
    led = CRGB::Black;
    FastLED.show();

    // reassign old states
    RLHT_old.heatSetpoint_1 = RLHT_old.heatSetpoint_1;
    RLHT_old.heatSetpoint_2 = RLHT_old.heatSetpoint_2;
    RLHT_old.rOnTime_1 = RLHT_old.rOnTime_1;
    RLHT_old.rOnTime_2 = RLHT_old.rOnTime_2;

    E_STOP = false;

    Serial.println("ESTOP RELEASED!");
  }
}

void setup()
{
  // put your setup code here, to run once:
  Serial.begin(115200);
  FastLED.addLeds<NEOPIXEL, LED_PIN>(&led, 1);

  pinMode(ESTOP, INPUT);
  attachInterrupt(digitalPinToInterrupt(ESTOP), estop, CHANGE);

  pinMode(RELAY1, OUTPUT);
  pinMode(RELAY2, OUTPUT);

  Wire.begin(I2C_ADR);
  Wire.onRequest(requestEvent);
  Wire.onReceive(receiveEvent);

  // tell the PID to range between 0 and the full window size
  relay1PID.SetOutputLimits(0, RLHT.rPeriod_1);
  relay2PID.SetOutputLimits(0, RLHT.rPeriod_2);

  // turn the PID on
  relay1PID.SetMode(AUTOMATIC);
  relay2PID.SetMode(AUTOMATIC);

  relay1StartTime = millis();
  relay2StartTime = millis();

  delay(2000);
}

void loop()
{
  // put your main code here, to run repeatedly:

  measureThermocouples();
  serialCommandHandler();
  printOutput();

  if (!E_STOP && currentMode == CONTROL)
  {
    setPIDTunings();
    // assign thermocouple readings to relay inputs
    switch (RLHT.thermoSelect[0])
    {
    case 1: // thermocouple 1 to relay 1
      RLHT.relay1Input = RLHT.thermo1;
      break;
    case 2: // thermocouple 2 to relay 1
      RLHT.relay1Input = RLHT.thermo2;
      break;
    }
    if (isnan(RLHT.relay1Input))
      RLHT.rOnTime_1 = 0;
    else
      relay1PID.Compute();

    switch (RLHT.thermoSelect[1])
    {
    case 1: // thermocouple 1 to relay 2
      RLHT.relay2Input = RLHT.thermo1;
      break;
    case 2: // thermocouple 2 to relay 2
      RLHT.relay2Input = RLHT.thermo2;
      break;
    }
    if (isnan(RLHT.relay2Input))
      RLHT.rOnTime_2 = 0;
    else
      relay2PID.Compute();

    actuateRelays();
  }
  else if (currentMode == WRITE)
  {
    actuateRelays();
  }
  else
  {
    digitalWrite(RELAY1, LOW);
    digitalWrite(RELAY2, LOW);
    Serial.println(F("ERROR, UNKNOWN STATE!"));
  }
}

void setPIDTunings()
{
  relay1PID.SetTunings(RLHT.Kp_1, RLHT.Ki_1, RLHT.Kd_1);
  relay2PID.SetTunings(RLHT.Kp_2, RLHT.Ki_2, RLHT.Kd_2);
}

void printOutput()
{
  if (millis() - lastSerialPrint >= SERIAL_UPDATE_TIME_MS)
  {
    Serial.print(F("Mode: "));
    Serial.print(currentMode == CONTROL ? "CONTROL" : "WRITE");
    Serial.print(F(", T1:"));
    Serial.print(RLHT.thermo1);
    Serial.print(F(", T2:"));
    Serial.print(RLHT.thermo2);

    Serial.print(F(", PID1:"));
    Serial.print(RLHT.Kp_1);
    Serial.print(F(","));
    Serial.print(RLHT.Ki_1);
    Serial.print(F(","));
    Serial.print(RLHT.Kd_1);

    Serial.print(F(", Relay1Input:"));
    Serial.print(RLHT.relay1Input);
    Serial.print(F(", Setpoint1:"));
    Serial.print(RLHT.heatSetpoint_1);
    Serial.print(F(",onTime1:"));
    Serial.print((int)RLHT.rOnTime_1);

    Serial.print(F(", PID2:"));
    Serial.print(RLHT.Kp_2);
    Serial.print(F(","));
    Serial.print(RLHT.Ki_2);
    Serial.print(F(","));
    Serial.print(RLHT.Kd_2);

    Serial.print(F(", Relay2Input:"));
    Serial.print(RLHT.relay2Input);
    Serial.print(F(", Setpoint2:"));
    Serial.print(RLHT.heatSetpoint_2);
    Serial.print(F(", onTime2:"));
    Serial.println((int)RLHT.rOnTime_2);

    lastSerialPrint = millis();
  }
}

void serialCommandHandler()
{
  if (Serial.available())
  {
    String command = Serial.readStringUntil('\n'); // Read serial input until newline
    command.trim();                                // Remove whitespace

    Serial.println("Received command: " + command);

    char cmdType = command.charAt(0); // First character determines command type

    if (cmdType == 'M') // Mode
    {
      int mode = command.charAt(2) - '0'; // 0 = CONTROL, 1 = WRITE

      if (mode == 0)
      {
        currentMode = CONTROL;
        relay1PID.SetMode(AUTOMATIC); // Turn on PID
        relay2PID.SetMode(AUTOMATIC);
        Serial.println(F("Switched to CONTROL mode"));
      }
      else if (mode == 1)
      {
        currentMode = WRITE;
        relay1PID.SetMode(WRITE); // Turn off PID
        relay2PID.SetMode(WRITE);
        Serial.println(F("Switched to WRITE mode"));
      }
    }
    else if (cmdType == 'W') // Write relay input
    {
      if (currentMode == WRITE)
      {
        int relay = command.charAt(2) - '0';           // 1 or 2
        double input = command.substring(4).toFloat(); // Extract relay input

        // limit it from 0 to 100
        input = (input < 0) ? 0 : (input > 100) ? 100
                                                : input;
        // cast the input to an integer
        int newOnTime = (int)input;

        if (relay == 1)
        {
          // scale from 0 to 100 to 0 to rPeriod
          newOnTime = map(newOnTime, 0, 100, 0, RLHT.rPeriod_1);
          RLHT.rOnTime_1 = newOnTime;
          Serial.print(F("Relay 1 input updated to: "));
        }
        else if (relay == 2)
        {
          // scale from 0 to 100 to 0 to rPeriod
          newOnTime = map(newOnTime, 0, 100, 0, RLHT.rPeriod_2);
          RLHT.rOnTime_2 = newOnTime;
          Serial.print(F("Relay 2 input updated to: "));
        }
        Serial.println(input);
      }
      else
      {
        Serial.println(F("ERROR: Not in WRITE mode!"));
      }
    }
    else if (cmdType == 'H') // Heater Setpoint
    {
      int heater = command.charAt(2) - '0';             // Heater number (1 or 2)
      double setpoint = command.substring(4).toFloat(); // Extract temperature setpoint

      if (heater == 1)
      {
        RLHT.heatSetpoint_1 = setpoint;
        Serial.print(F("Heater 1 setpoint updated to: "));
      }
      else if (heater == 2)
      {
        RLHT.heatSetpoint_2 = setpoint;
        Serial.print(F("Heater 2 setpoint updated to: "));
      }
      Serial.println(setpoint);
    }
    else if (cmdType == 'P') // PID Tuning
    {
      int heater = command.charAt(2) - '0';
      int firstComma = command.indexOf(',', 4);
      int secondComma = command.indexOf(',', firstComma + 1);
      int thirdComma = command.indexOf(',', secondComma + 1);

      double Kp = command.substring(4, firstComma).toFloat();
      double Ki = command.substring(firstComma + 1, secondComma).toFloat();
      double Kd = command.substring(secondComma + 1, thirdComma).toFloat();

      if (heater == 1)
      {
        RLHT.Kp_1 = Kp;
        RLHT.Ki_1 = Ki;
        RLHT.Kd_1 = Kd;
        relay1PID.SetTunings(Kp, Ki, Kd);
        Serial.print("PID Heater 1 updated: ");
      }
      else if (heater == 2)
      {
        RLHT.Kp_2 = Kp;
        RLHT.Ki_2 = Ki;
        RLHT.Kd_2 = Kd;
        relay2PID.SetTunings(Kp, Ki, Kd);
        Serial.print("PID Heater 2 updated: ");
      }
      Serial.print("Kp = ");
      Serial.print(Kp);
      Serial.print(", Ki = ");
      Serial.print(Ki);
      Serial.print(", Kd = ");
      Serial.println(Kd);
    }
    else if (cmdType == 'S') // Thermo select
    {
      int relay = command.charAt(2) - '0';
      char thermo = command.charAt(4);

      if (relay == 1)
      {
        RLHT.thermoSelect[0] = thermo;
        Serial.print("ThermoSelect 1 updated: ");
      }
      else if (relay == 2)
      {
        RLHT.thermoSelect[1] = thermo;
        Serial.print("ThermoSelect 2 updated: ");
      }
      Serial.println(thermo);
    }
    else
    {
      Serial.println("Invalid command!");
    }
  }
}

void measureThermocouples()
{
  if (millis() - lastThermoRead >= THERMO_UPDATE_TIME_MS)
  {
    RLHT.thermo1 = CH1.readCelsius();
    RLHT.thermo2 = CH2.readCelsius();
    lastThermoRead = millis();
  }
}

void actuateRelays()
{
  if (RLHT.heatSetpoint_1 == 0 && currentMode == CONTROL)
    RLHT.rOnTime_1 = 0;
  if (RLHT.heatSetpoint_2 == 0 && currentMode == CONTROL)
    RLHT.rOnTime_2 = 0;
  // Relay 1
  if (millis() - relay1StartTime > RLHT.rPeriod_1)
  { // time to shift the Relay Window
    relay1StartTime += RLHT.rPeriod_1;
  }
  if ((int)(RLHT.rOnTime_1) > millis() - relay1StartTime)
    digitalWrite(RELAY1, HIGH);
  else
    digitalWrite(RELAY1, LOW);

  // Relay 2
  if (millis() - relay2StartTime > RLHT.rPeriod_2)
  { // time to shift the Relay Window
    relay2StartTime += RLHT.rPeriod_2;
  }
  if ((int)(RLHT.rOnTime_2) > millis() - relay2StartTime)
    digitalWrite(RELAY2, HIGH);
  else
    digitalWrite(RELAY2, LOW);
}

void requestEvent()
{
  FLOATUNION_t t1;
  FLOATUNION_t t2;

  if (isnan(RLHT.thermo1))
    t1.number = 0;
  else
    t1.number = RLHT.thermo1;

  if (isnan(RLHT.thermo2))
    t2.number = 0;
  else
    t2.number = RLHT.thermo2;

  for (int i = 0; i < 4; i++)
    Wire.write(t1.bytes[i]);
  for (int i = 0; i < 4; i++)
    Wire.write(t2.bytes[i]);
}

/* Command layout
  Byte 1:     T (want temperature reading)
              H (change heater setpoint)
              P (change PID tuning)
  Byte 2:     1 (first heater/thermocouple)
              2 (second heater/thermocouple)
  Byte 3-6:   Kp or heatSetpoint
  Byte 7-10:  Ki
  Byte 11-14: Kd
*/

void receiveEvent(int howMany)
{
  byte in_char;
  char in_TC_DATA[20];

  led = CRGB::Green;
  FastLED.show();

  // Serial.println("Receiving: ");
  int i = 0;
  while (Wire.available())
  {
    in_char = Wire.read();
    in_TC_DATA[i] = in_char;
    Serial.print((byte)in_TC_DATA[i]);
    Serial.print(",");
    i++;
  }
  Serial.println();

  setParametersRLHT(in_TC_DATA);

  led = CRGB::Black;
  FastLED.show();
}

/*
RLHT Command Format:
  H,1,setpoint,2,0:   temperature setpoint between relay 1 and thermo 2. Enable reverse response = 0 (false)
  P,Kp,Ki,Kd:       PID tuning
*/

void setParametersRLHT(char *in_TC_DATA)
{
  FLOATUNION_t float1;
  FLOATUNION_t float2;
  FLOATUNION_t float3;

  switch (in_TC_DATA[0])
  {
  case 'H':
    for (int i = 0; i < 4; i++)
      float1.bytes[i] = in_TC_DATA[i + 2];
    if (in_TC_DATA[1] == 1)
    {
      RLHT.heatSetpoint_1 = float1.number;
      RLHT.thermoSelect[0] = in_TC_DATA[6];
      relay1PID.SetControllerDirection(in_TC_DATA[7]); // Direct = 0, Reverse = 1
    }
    if (in_TC_DATA[1] == 2)
    {
      RLHT.heatSetpoint_2 = float1.number;
      RLHT.thermoSelect[1] = in_TC_DATA[6];
      relay2PID.SetControllerDirection(in_TC_DATA[7]); // Direct = 0, Reverse = 1
    }
    break;
  case 'P':
    for (int i = 0; i < 4; i++) // populate variables for PID tuning
    {
      float1.bytes[i] = in_TC_DATA[i + 2];
      float2.bytes[i] = in_TC_DATA[i + 6];
      float3.bytes[i] = in_TC_DATA[i + 10];
    }
    if (in_TC_DATA[1] == 1)
    {
      RLHT.Kp_1 = (double)float1.number;
      RLHT.Ki_1 = (double)float2.number;
      RLHT.Kd_1 = (double)float3.number;
    }
    if (in_TC_DATA[1] == 2)
    {
      RLHT.Kp_2 = (double)float1.number;
      RLHT.Ki_2 = (double)float2.number;
      RLHT.Kd_2 = (double)float3.number;
    }
    break;
  }
}

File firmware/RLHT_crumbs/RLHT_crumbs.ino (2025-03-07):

#include <Wire.h>
#include "max6675.h"
#include <FastLED.h>
#include <PID_v1.h>

// BREAD specific libs
#include <CRUMBS.h>

// internal libs
#include "hardware_config.h"
#include "config.h"

/**
 * @def SLICE_PRINT
 * @brief Uncomment to enable print messages.
 */

#define SLICE_PRINT 1

#ifdef SLICE_PRINT

#define SLICE_PRINT(...) \
  Serial.print(__VA_ARGS__)

#define SLICE_PRINTLN(...) \
  Serial.println(__VA_ARGS__)

#else
#define SLICE_PRINT(...)
#define SLICE_PRINTLN(...)
#endif

/**
 * @def SLICE_DEBUG
 * @brief Uncomment to enable additional debugging messages.
 */

// #define SLICE_DEBUG 1

#ifdef SLICE_DEBUG

#define SLICE_DEBUG_PRINT(...) \
  Serial.print(__VA_ARGS__)

#define SLICE_DEBUG_PRINTLN(...) \
  Serial.println(__VA_ARGS__)

#else
#define SLICE_DEBUG_PRINT(...)
#define SLICE_DEBUG_PRINTLN(...)
#endif

struct RelayHeaters
{
  double heatSetpoint_1 = 0; // set desired temperature for heater 1 (if using relay as heater actuator)
  double relay1Input;        // input to relay 1 taken from selected thermocouple
  double rOnTime_1;          // time relay is on in ms (0-period)
  int rPeriod_1 = 2000;      // duration of relay 1 cycle in ms (1000ms = 1s)
  double Kp_1 = 0;           // PID proportional gain for heater 1
  double Ki_1 = 0;           // PID integral gain for heater 1
  double Kd_1 = 0;           // PID derivative gain for heater 1
  double heatSetpoint_2 = 0;
  double relay2Input;
  double rOnTime_2;
  int rPeriod_2 = 2000;
  double Kp_2 = 0;
  double Ki_2 = 0;
  double Kd_2 = 0;
  double thermo1; // thermocouple 1 measurement
  double thermo2;
  char thermoSelect[2] = {1, 2}; // select which thermocouples pair with relays {relay1, relay2}
  bool eStop = false;            // emergency stop flag
};

RelayHeaters RLHT_curr, RLHT_prev;

struct Timing
{
  long lastThermoRead;
  long lastSerialPrint;
  unsigned long relay1Start;
  unsigned long relay2Start;
} timing = {0};

volatile bool estopTriggered = false;

// create object for the LED
CRGB led;

// initialize the Thermocouples
MAX6675 thermocouple1(TC_CLK, TC_CS1, TC_DATA);
MAX6675 thermocouple2(TC_CLK, TC_CS2, TC_DATA);

// Specify the links and initial tuning parameters
// PID myPID(&Input, &Output, &Setpoint, Kp, Ki, Kd, DIRECT);
PID relay1PID(&(RLHT_curr.relay1Input), &(RLHT_curr.rOnTime_1), &(RLHT_curr.heatSetpoint_1), RLHT_curr.Kp_1, RLHT_curr.Ki_1, RLHT_curr.Kd_1, DIRECT);
PID relay2PID(&(RLHT_curr.relay2Input), &(RLHT_curr.rOnTime_2), &(RLHT_curr.heatSetpoint_2), RLHT_curr.Kp_2, RLHT_curr.Ki_2, RLHT_curr.Kd_2, DIRECT);

enum Mode
{
  CONTROL,
  WRITE
} currentMode = CONTROL;

// CRUMBS start
CRUMBS crumbsSlice(false, I2C_ADR); // Slave mode, I2C address 0x08

void setup()
{
  // the general slice setup
  setupSlice();

  // the RLHT specific setup
  setupRLHT();

  // small delay before entering loop
  delay(1000);
}

void setupSlice()
{
  // initialize serial communication
  Serial.begin(115200);

  // Initialize CRUMBS communication
  crumbsSlice.begin();

  crumbsSlice.onRequest(handleRequest); // Register callback for data requests
  crumbsSlice.onReceive(handleMessage); // Register callback for received messages

  // initialize the LED
  FastLED.addLeds<NEOPIXEL, LED_PIN>(&led, 1);

  // initialize the estop
  pinMode(ESTOP, INPUT);
  attachInterrupt(digitalPinToInterrupt(ESTOP), estopISR, CHANGE);
}

void setupRLHT()
{
  // initialize the relay pins
  pinMode(RELAY1, OUTPUT);
  pinMode(RELAY2, OUTPUT);

  // tell the PID to range between 0 and the full window size
  relay1PID.SetOutputLimits(0, RLHT_curr.rPeriod_1);
  relay2PID.SetOutputLimits(0, RLHT_curr.rPeriod_2);

  // turn the PID on
  relay1PID.SetMode(AUTOMATIC);
  relay2PID.SetMode(AUTOMATIC);

  // initialize the relay start times
  timing.relay1Start = millis();
  timing.relay2Start = millis();
}

void loop()
{

  // poll the emergency stop
  pollEStop();

  // read the thermocouples
  measureThermocouples();

  // main control logic
  relayControlLogic();

  // print output to serial
  printSerialOutput();
}

void pollEStop()
{
  if (estopTriggered)
  {
    // Update LED to indicate emergency stop
    led = CRGB::Red;
    FastLED.show();
    processEStop();
    estopTriggered = false; // Reset flag after handling
  }
  else
  {
    // Update LED to indicate normal operation
    led = CRGB::Green;
    FastLED.show();
  }
}

void estopISR()
{
  estopTriggered = true;
}

void processEStop()
{
  // Read the current state of the estop pin if needed for debouncing/validation
  if (digitalRead(ESTOP) == HIGH)
  {
    // Disable PID and turn off relays safely
    RLHT_curr.heatSetpoint_1 = 0;
    RLHT_curr.heatSetpoint_2 = 0;
    RLHT_curr.rOnTime_1 = 0;
    RLHT_curr.rOnTime_2 = 0;
    digitalWrite(RELAY1, LOW);
    digitalWrite(RELAY2, LOW);

    // Set the emergency stop flag in the system
    RLHT_curr.eStop = true;
    SLICE_DEBUG_PRINTLN("ESTOP PRESSED!");
  }
  else
  {
    // If the button/switch is released, restore or handle recovery
    led = CRGB::Green;
    FastLED.show();

    // Optionally restore previous settings or require a manual reset
    RLHT_curr.eStop = false;
    SLICE_DEBUG_PRINTLN("ESTOP RELEASED!");
  }
}
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

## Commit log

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2026-03-18 tighten type to unsigned on relayPeriod and centralized period writer
    [main.cpp]
2026-03-19 remove duplicate (drift prone) version in favour of the canonical version defined in contract
    [main.cpp]
2026-03-19 fix: thermocouple timing drift by using relative interval updates and replace raw INT16_MIN sentinel with protocol-defined BREAD_INVALID_I16
    [main.cpp]
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2026-05-12 fix(fw): protect shared state with interrupt guards
    Defer setRelayPeriod side-effects to main loop (PID not ISR-safe).
    Snapshot ISR-written command fields atomically in relayControlLogic.
    Add noInterrupts/interrupts guards in processEStop writes.
    [main.cpp]
2026-05-12 fix(fw): replace String with static buffer in serial commands
    Eliminates all heap allocations from the serial command parser.
    Uses a 64-byte static char buffer and C string functions (atol,
    atof, strcmp_P) to prevent heap fragmentation on long-running
    ATmega328 devices.
2026-05-12 fix(fw): use unsigned long for timing fields
    Matches millis() return type, prevents signed overflow after ~24 days.
2026-05-12 fix(fw): guard empty string trim, remove no-op relay commit
    [main.cpp]
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2026-07-14 refactor(firmware): split relayControlLogic snapshot cli window (#3)
    Split the single ~44-byte interrupt-masked snapshot into three short
    windows (estop/mode/setpoints, heater1 tunings, heater2 tunings; worst
    case ~18 bytes). Long noInterrupts() windows delay TWI ISR entry at
    the SLA+R boundary and force a clock stretch that Linux SBC I2C
    masters mishandle - the confirmed cause of the DCMT query failures
    (feastorg/Slice_DCMT#3). Per-heater fields stay in one window so a
    heater's tunings are never torn; a torn view across windows
    self-corrects next iteration.
    Preventive hardening: RLHT measured 0 wire-query failures in bench
    testing, but its snapshot was the same hazard class.
    [main.cpp]
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2026-07-18 fix: stamp watchdog liveness in every reply builder (#7)
    Same defect as feastorg/Slice_DCMT#9: only the GET_WATCHDOG reply
    builder stamped wdLastRxMs, so the controller's 1 Hz GET_STATE polls
    never fed the watchdog (SET_REPLY staging frames are excluded from
    on_message) and an armed idle board tripped 5 s after arming. Stamp
    in all reply builders per the design in #5.
2026-09-10 chore: mechanical remediation (KiCad 10, DRC gate, Makefile, gitignore) (#2)
    Fleet-wide mechanical pass. **No library or design changes** — not a
    single part is altered.
    Each step is a separate commit so any one can be reverted independently.
    Please **merge, do not squash**, so the per-step history survives.
    ## Commits
    - `f900547` chore: gitignore KiCad 10 local history
    - `3d0cb3e` fix(hw): fail DRC on schematic/PCB footprint mismatch
    - `2441409` fix(hw): un-swap the ERC and DRC Makefile targets
    - `d2eac92` chore(hw): migrate KiCad files to the KiCad 10 format
    ## What each one fixes
    | | |
    | --- | --- |
    | **KiCad 10** | Via `kicad-cli sch upgrade` / `pcb upgrade`. Verified
    lossless on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
    [thermistor.kicad_sch]
2026-10-04 fix(firmware): clear the PID integral when a heater goes off (#16)
    Fixes #13: a heater now stops at once on the safe state, a watchdog trip
    or an e-stop, and starts from 0 when a setpoint returns.
    The PID integral survived `SET_SETPOINTS(0, 0)`, a command-watchdog trip
    and an e-stop. A heater kept running after the safe state, and resumed
    its old duty when a trip cleared or an e-stop was released. The duty
    decayed only through Ki, over tens of seconds, and never with Ki = 0.
    ## The change
    - **`computeHeater()`, closed loop.** A heater whose setpoint is 0 or
    less is held at an on-time of 0, with its PID in manual. PID_v1
    re-initialises the integral from the output when it returns to
    automa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
    [main.cpp]
2026-10-08 fix(firmware): drop the phantom second relay on gen1 (#23)
    Closes #21.
    Gen1 boards (the four OSF boards under `archive/hw_archive/`) have one
    relay, on D6, and D7 is not connected. The gen1 profile defined `RELAY2
    7` anyway, so it drove D7 at channel 2's duty, and `GET_STATE` reported
    a second heater running.
    - `RLHT_RELAY_COUNT` is 1 on gen1 and 2 on gen2. `RELAY2` is defined
    only on gen2, so gen1 code that touches D7 fails to compile.
    - On gen1, channel-2 commands are still accepted (wire format
    unchanged), but channel 2 is never computed or actuated, and `GET_STATE`
    reports it off with a 0 on-time.
    - The four repeated `RELAY1`/`RELAY2` LOW pairs become `relaysLow()`, so
    the guard sits i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
    [config_hardware.h, main.cpp]
2026-10-08 fix(firmware): stop relayControlLogic writing its snapshot back (#24)
    Closes #14, closes #17. On top of #23, now merged.
    `relayControlLogic()` copied mode, setpoints, PID gains, thermocouple
    selects and the open-loop on-times, then wrote the copies back over
    anything the I2C handlers wrote in between. On a gen1 rig (see #14) 10
    of 16 open-loop duty frames were lost this way, duty 0/0 among them, so
    a controller's safe state did not stop the heater.
    ## Changes
    - The PIDs work on their own input, setpoint and output variables
    instead of pointers into `slice`.
    - `relayControlLogic()` only reads the handler-written fields. All five
    write-backs are gone.
    - Closed loop publishes the PID output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
    [main.cpp]
2026-10-13 feat(firmware): codec adoption and a latched watchdog trip (#18)
    Closes #11, closes #9. Refs feastorg/Slice_DCMT#26.
    `platformio.ini` pins `bread-crumbs-contracts @ ^0.6.0` and `CRUMBS @
    ^0.14.0`; contracts 0.6.0 (feastorg/bread-crumbs-contracts#29 + #30) is
    on the PlatformIO registry and the Firmware Build workflow resolves it.
    Rebased onto `main` after #23 and #24 merged. Two conflicts, both kept
    from each side: `handler_set_mode` keeps the codec unpack and #24's
    open-loop-starts-at-0 (after the trip check), and `processEStop` keeps
    #23's `relaysLow()` (gen1 defines no `RELAY2`) with this branch's
    comment.
    ## Codec (#11)
    The SET handlers unpack with the contracts' generated `rlht_*_unp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
2026-10-16 fix(firmware): require RLHT_HW_GEN instead of defaulting to gen2 (#30)
    This ports the DCMT fix, feastorg/Slice_DCMT#41, to RLHT.
    `firmware/include/config.h` defined `RLHT_HW_GEN` as 2 when the build
    flag was absent. `config_hardware.h` includes `config.h` first, so its
    `#error "Unsupported RLHT_HW_GEN value"` could only reject an
    out-of-range value, never a missing one, and `pio run -e nano_base`
    built the gen2 profile without a warning. On a gen1 board that drives
    the unconnected D5 and D7.
    - `config.h`: a missing `RLHT_HW_GEN` is now an `#error` that points to
    the `gen*` envs in `firmware/platformio.ini`.
    - `firmware-build.yml`: on the `gen2_nano` leg, a step preprocesses
    `config.h`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
2026-10-19 fix(firmware)!: move the default I2C address to 0x13 (#33)
    Moves the default I2C address from 10 (0x0A) to 19 (0x13). 0x0A is
    inside 0x08-0x0B, the SMBus range CRUMBS's `docs/protocol.md` says to
    avoid; 0x13 is outside every range it lists.
    The default appears in three places in the active firmware and metadata,
    and all three change:
    - `firmware/include/config.h`: `#define I2C_ADR 10` -> `19`, with a
    comment citing #12
    - `firmware/platformio.ini`: the `; -DI2C_ADR=10` example -> `19`
    - `slice.yaml`: `address_default: 10` -> `19`
    `README.md`, `firmware/README.md` and `docs/` never name the address, so
    they don't change. The six `#define I2C_ADR 10` lines under
    `archive/fw_archive/` stay as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
2026-10-19 fix(firmware): refuse the SETs the firmware drops (#35)
    Every SET the firmware does not act on in full is now refused with
    `crumbs_refuse()` and a reason from bread-crumbs-contracts
    `bread_refuse.h`, so GET_ACK reports it refused instead of applied.
    Before this, no handler called `crumbs_refuse()`, and
    `on_crumbs_message`, registered as `on_message` for the watchdog stamp,
    made CRUMBS count every decoded frame as applied (#34). The same pattern
    was measured on DCMT in feastorg/Slice_DCMT#43; on rlht0 only the
    applied side was measured, as the issue says.
    | Reason | Where |
    | `MALFORMED` | any `*_unpack` failure; SET_WATCHDOG without its u16;
    CLEAR_WATCHDOG_TRIP with a payload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
2026-10-20 fix(firmware): assert the e-stop on the first LOW sample (#38)
    `pollEStop()` restarted its 25 ms debounce timer on every edge of the
    e-stop line, so edges less than 25 ms apart kept `processEStop()` from
    running for as long as they lasted, whatever the line's level (#29).
    - `pollEStop()` now samples the line on every loop pass. The first LOW
    sample asserts the e-stop; release needs 25 ms with no LOW sample. A
    line that keeps chattering after a release stays stopped.
    - `processEStop(bool pressed)` takes the debounced state instead of
    re-reading a pin that may have bounced since. The CHANGE interrupt,
    which only set a flag, is removed along with `estopTriggered` and
    `estopISR()`.
    - `setup()`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
2026-10-20 feat(firmware): refuse heat-starting commands while the e-stop is held (#40)
    Implements `RLHT_CAP_ESTOP_HOLD` (bread-crumbs-contracts 0.10.0,
    feastorg/bread-crumbs-contracts#57).
    **The problem** (#37). The press zeroed the setpoints and on-times and
    turned the relays off, but `SET_MODE`, `SET_SETPOINTS` and
    `SET_OPEN_DUTY` sent during the hold were stored, so releasing the line
    heated to them.
    **The change.**
    - While the line is held, those three are refused with
    `BREAD_REFUSE_ESTOP`. One helper, `hold_refuse_reason()`, names the hold
    for all three, and `ESTOP` wins over `WATCHDOG_TRIP`. RLHT still checks
    the hold before unpacking, as it already did for the trip, so a short
    frame during a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
2026-10-20 fix(firmware): refuse GET opcodes as commands and reject other families' frames (#41)
    Fixes the two gaps #36 describes.
    **GET opcodes sent as command frames** (#36). `is_defined_op()` was
    built from `RLHT_OPS` and `BREAD_COMMON_OPS`, which also hold GET_STATE
    (0x80), GET_WATCHDOG (0x7D) and GET_CAPS (0x7F). Those are queries
    answered through SET_REPLY, so as a command frame nothing handled them,
    and `on_message` taking the frame made GET_ACK report APPLIED.
    `is_command_op()` now lists the eight opcodes `setupSlice()` registers a
    command handler for, so the GET opcodes are refused with
    `BREAD_REFUSE_UNKNOWN_OP`. A query added to the contract later can't
    read APPLIED either.
    **Frames typed f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
2026-10-20 build(pio): pin the atmelavr and atmelmegaavr platforms (#43)
    `platform = atmelavr` and `platform = atmelmegaavr` named no version, so
    every clean build and CI run took the newest platform release. The
    compiler and Arduino core could change between two builds of the same
    commit with no change in the repo.
    This pins them to the versions builds already resolve:
    - `platformio/atmelavr @ 5.3.0`
    - `platformio/atmelmegaavr @ 1.10.0`
    Both are the latest in the PlatformIO registry
    (`api.registry.platformio.org/v3/packages/platformio/platform/<name>`:
    atmelavr 5.3.0 released 2026-06-23, atmelmegaavr 1.10.0 released
    2026-04-28). The CI run on feastorg/Slice_RLHT#41 (run 39447685178)
    logged `Atmel A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
2026-10-20 fix(firmware): keep the status LED blue through the boot wait (#46)
    The gen2 status LED never shows blue at boot. The same bug showed on a
    gen2 DCMT Nano on the bench (straight to green at power-up and on
    reset); RLHT has the same boot wait and LED code.
    **Cause.** Since the e-stop sampling change (#38), the 1 s boot wait in
    `setup()` calls `pollEStop()` instead of `delay(1000)`. `pollEStop()`
    also wrote the status LED, so its first pass, microseconds after the
    boot blue, wrote green, or red with the e-stop held. Before #38, blue
    held for the `delay(1000)`.
    **Fix.** The LED update moves out of `pollEStop()` into
    `updateStatusLed()`, called from `loop()` only, right after
    `pollEStop()`:
    -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
2026-10-23 refactor(firmware): move e-stop, watchdog and LED onto bread-slice-core (#57)
    RLHT takes its e-stop input, command watchdog and status LED from
    bread-slice-core 0.1 (feastorg/.github#4), as Slice_DCMT did in
    feastorg/Slice_DCMT#77.
    - `bsc::EStop` and `bsc::bootWait()` replace `pollEStop()`,
    `slice.eStop` and `estopCount`. `processEStop()` keeps RLHT's setpoint,
    on-time, relay and PID handling and runs on the `Pressed` event.
    - `bsc::CommandWatchdog` replaces the `wd*` globals in the I2C handlers,
    serial `WDOG=`/`WDCLEAR` and `watchdogLogic()`. The trip action is
    unchanged.
    - `bsc::StatusLed` replaces FastLED on gen2. FastLED is gone from
    `platformio.ini` and `slice.yaml`.
    Behaviour changes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
2026-10-24 fix(firmware): handle one serial line per loop pass (#58)
    `serialCommands()` returns after one complete line, so a burst is
    answered one line per `loop()` pass and the e-stop is sampled between
    lines. This is the fix Slice_DCMT has had since feastorg/Slice_DCMT#49.
    `test_serial_burst` sends five `R1TIME=` lines at once in open loop,
    then a press mid-burst:
    - before: three checks failed on all four envs. One pass answered the
    whole burst, nothing was left buffered, and the line after the press was
    applied;
    - after: all 24 runs pass (6 tests, 4 envs), and all four envs build.
    Not measured on a board: the latency #39 estimates from the code. Bench
    check from the issue: stream invalid lines w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
2026-10-24 fix(firmware): parse serial numbers strictly (#59)
    Every serial number goes through bread-slice-core's `parseLong()` or
    `parseFloat()`. The whole token must parse and be in range for its
    field, or the command is refused with its existing message and nothing
    changes. This is the RLHT half of feastorg/Slice_DCMT#79.
    | Field | Range |
    | `R1TEMP=`, `R2TEMP=` | 0 to 500, closed loop (unchanged) |
    | `R1TIME=`, `R2TIME=` | 0 to the relay period, open loop (unchanged) |
    | `R1TC=`, `R2TC=` | 1 or 2 (unchanged) |
    | `R1KP=` ... `R2KD=` | 0 to 25.5, SET_PID's range (u8 x10); any value
    >= 0 before |
    | `R1PERIOD=`, `R2PERIOD=` | `RLHT_PERIOD_MIN_MS` to
    `RLHT_PERIOD_MAX_MS` (unchanged) |
    | `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
2026-10-24 fix(firmware): take serial gains up to 65.535 (#61)
    #59 capped serial gains at 25.5, the u8 x10 range of today's SET_PID;
    before it, any gain >= 0 was taken. A relay heater's output is on-time
    in ms, so Kp is in ms per degree and a working tune can sit above 25.5.
    Serial was the only way to set one, and #59 took that away.
    The ceiling is now 0 to 65.535, the u16 x1000 range
    bread-crumbs-contracts#64 proposes for SET_PID. Serial stays as wide as
    that planned wire format and never takes a gain it couldn't carry.
    `test_serial_numbers` now applies `R1KP=50` and refuses `R1KP=70`. With
    the `R1KP=` ceiling put back at 25.5, the `R1KP=50` check fails on all
    four envs. All 28 runs pass, and all fo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
2026-10-25 feat(firmware): refuse setpoints in open loop and above a ceiling (#64)
    SET_SETPOINTS stored any i16 deci-degree value in either mode. One
    above the MAX6675's range could never be reached, and one sent in open
    loop started heating at the next switch to closed loop. Serial R1TEMP=
    and R2TEMP= already refused both.
    Now SET_SETPOINTS is refused WRONG_MODE outside closed loop and
    UNDEFINED_VALUE above RLHT_SETPOINT_MAX_C (build flag, default 500 C),
    storing neither setpoint. Serial takes its ceiling from the same
    constant, with the same reply text at the default. A negative setpoint
    is still accepted and is off. GET_CAPS advertises
    RLHT_CAP_SETPOINT_LIMITS (bread-crumbs-contracts 0.11.0).
    test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
2026-10-26 feat(firmware): latch heater faults and hold both heaters off (#65)
    Only a NaN reading stopped a heater, and for that pass only. A probe
    shorted at the leads or off the heated part reads as a valid
    temperature, so the PID stayed at full output, and nothing bounded the
    temperature in open loop.
    Three faults now latch per heater, on the thermocouple it is set to:
    over-temperature in either mode (RLHT_OVERTEMP_C, default 525 C); no
    rise in closed loop (output at or above 90 % for 120 s with under 2 C of
    rise); and, in closed loop with a setpoint, 3 open-thermocouple readings
    in a row. A heater with no setpoint, or in open loop, can run with its
    probe unplugged. Gen1 checks heater 1 only. Every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
2026-10-26 feat(firmware): take SET_PID gains as u16 x1000 (#67)
    SET_PID carried six u8 gains x10: 0 to 25.5 in steps of 0.1, coarser
    and lower than a heater can need, and lower than serial's 0 to 65.535.
    A 12-byte SET_PID now carries six u16 gains x1000 (0 to 65.535) beside
    the 6-byte form; any other length is still refused MALFORMED. GET_CAPS
    advertises RLHT_CAP_PID_X1000 (bread-crumbs-contracts 0.11.0, #64
    there). Flash grows 360 B.
    test_set_pid_length now applies 12 bytes as x1000 (50.000, 0.125,
    1.003, and the u16 maximum 65.535) where it used to expect a refusal,
    and refuses 5, 7, 11 and 13 bytes. Each of 5 mutations fails it: 12
    bytes read as x10, 12 bytes refused, 13 bytes accepted, Kp and Ki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
2026-10-26 docs(bench): add the 2026-10-25 record (#68)
    Plan for tonight's bench on the gen2 Nano at main 236a0c2: #64 (setpoint
    limits), #65 (heater faults), #66 (watchdog lease) and #67 (12-byte
    SET_PID). The record's rlht_bench.py adds wdl, pid, pid6, faults,
    fclear, raw and watch. Also indexes the 2026-10-24 record, missing from
    docs/bench/README.md. Results are filled in at the bench.
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2026-10-26 fix(firmware): latch over-temperature after 3 readings in a row (#71)
    Over-temperature now latches after `RLHT_OVERTEMP_READS` consecutive
    readings above `RLHT_OVERTEMP_C` (default 3, about 0.9 s at the 300 ms
    read interval), not on one reading. A NaN or in-limit reading restarts
    the count. The count holds while the heater stays hot, so a clear while
    still over temperature latches again on the next reading, as before. A
    `static_assert` keeps the flag at 1 to 255, since the counter is a
    `uint8_t`.
    On the 2026-10-25 bench (#68, `main` image, limit 525 C) H1_OVERTEMP
    latched twice with both probes at room temperature: one 547.8 C reading
    while thermocouple 1 was unplugged, and once with the ri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
2026-10-26 refactor(firmware): refuse unhandled opcodes from the handler table (#72)
    `on_message` refused UNKNOWN_OP any opcode missing from
    `is_command_op()`, a list kept by hand beside the
    `crumbs_register_handler()` calls. It now asks CRUMBS with
    `crumbs_has_handler()` (feastorg/CRUMBS#124, released in 0.17.0). The
    registrations become the firmware's only list. `test_dispatch.cpp` keeps
    its own as the test's oracle. A command with no handler is now refused,
    where before it answered APPLIED with nothing behind it. That covers a
    failed registration, and a frame that lands between
    `crumbs_set_callbacks()` and its opcode's registration at boot. The
    second is a window a few registration calls long. This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
2026-11-01 fix(test): rebuild host tests when a library version changes (#75)
    `pio pkg install` keeps a release archive's mtimes, so after a pin
    change the newly installed CRUMBS sources look older than the objects
    built from the previous version. A plain `make -C test/host` then kept
    linking those objects. This is the same change as
    feastorg/Slice_DCMT#91.
    The Makefile now writes `build/libdeps.stamp` from the `.piopm` that
    PlatformIO writes in each registry package, which records its version.
    It reads them with a shell glob, so a package directory with a space in
    its name works. The stamp is rewritten only when its content changes.
    The CRUMBS objects and the test binaries depend on it, so a changed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
2026-11-01 fix(firmware): store the thermocouple readings with interrupts masked (#78)
    `reply_get_state()` reads `slice.temperature1` and `slice.temperature2`
    from the TWI ISR. `measureThermocouples()` stored each one as four byte
    stores with interrupts enabled. So a GET_STATE that landed mid-store
    reported a mix of the old and new value. The issue's example is 127.75
    °C changing to 128.0 °C and reported as 32.0 °C. Both readings are now
    taken first and stored together in one masked window, so the two
    temperatures in a reply also come from the same reading. Slice_DCMT
    already commits its measured fields this way.
    The masked window holds eight `sts` and nothing else. `readCelsius()`
    runs before it.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
2026-11-01 fix(firmware): compute the heater PIDs once per thermocouple reading (#76)
    The heater PIDs computed every 100 ms, PID_v1's default, on a
    thermocouple reading refreshed every 300 ms. So the derivative came as
    one impulse three times its size on the compute after each reading, then
    zero for two computes, and the relay's on-time followed it.
    `SetSampleTime(300)`, the issue's first suggestion, isn't enough by
    itself. PID_v1 times each compute from the previous one (`lastTime =
    now`), and each compute lands on the first loop pass past that time. So
    its schedule slips a little each reading against the readings, which are
    paced at a fixed 300 ms (`lastThermoRead += THERMO_UPDATE_TIME_MS`).
    When th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
2026-11-01 fix(firmware): refuse a thermocouple select change under a running heater (#77)
    Two changes to how a heater's PID gets its input.
    - **#28, a refactor.** `RelayHeater::inputTemperature` was scratch for
    `relayControlLogic()`. It was written by a `switch` on the select, and
    read by `computeHeater()` and the serial status line.
    `selectedTemperature()` replaces it, along with the `switch`es'
    `default:` arms, which no stored select reaches. `checkHeaterFaults()`
    uses the same function in place of its own ternaries. The status line's
    `Relay1Input`/`Relay2Input` now show the selected reading in open loop
    as well; the field used to keep the last closed-loop value there.
    - **#54, a fix.** A heater's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
2026-11-02 fix(firmware): take the control snapshot per reading, not per pass (#85)
    Fixes #81, the GET_STATE replies cut short on the gen2 Nano.
    The 2026-11-01 bisect (#84) traced the cut-short replies to how often
    the loop masks interrupts. With `main.cpp`'s masked windows removed, or
    with the loop slowed by 300 us a pass, the bad-reply rate went from 187
    in 300 s to 0. `relayControlLogic()` opened four masked windows on every
    pass: three snapshots and the on-time commit.
    What changes:
    - `relayControlLogic()` takes its snapshot, runs the PIDs and publishes
    the on-times only on a new thermocouple reading, or once
    `RLHT_SNAPSHOT_INTERVAL_MS` (default 10, a `-D` override) has passed. In
    between, `actu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
2026-11-04 docs: record gen1's ungrounded thermocouple T- and its rework (#87)
    In all four gen1 board files, each MAX6675's T- (pin 2) reaches only
    its filter capacitor, ferrite bead and terminal, never GND, though the
    datasheet says T- "should be connected to ground externally" and must
    be grounded for open-thermocouple detection. The gen1 boards in use
    carry a hand-soldered bridge from pin 1 (GND) to pin 2 on U3 and U4.
    docs/hardware-revisions.md now records both, notes that gen2 grounds T-
    in the layout and that the MAX31855K in hardware/ must not have T- on
    GND, and points to the gen1 cold-junction error (#86).
    Pins confirmed on the board in use: the bridge joins pin 1 and pin 2 on
    both U3 and U4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
